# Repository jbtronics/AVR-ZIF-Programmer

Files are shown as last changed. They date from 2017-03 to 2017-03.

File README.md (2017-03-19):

# AVR-ZIF-Programmer

An Universal AVR Programmer with a ZIF-Socket and ISP Header based on [USBasp by Thomas Fischl](http://www.fischl.de/usbasp/).
The PCB was designed in [KiCAD](http://kicad-pcb.org/)

## Features:
* based on USBasp by Thomas Fischl
* ISP-Connector on PCB
* can Program many different AVRs:
  * ATMega 164/324/644/1284/16/32
  * ATMega 8/48/88/168/328
  * ATTiny 2313/4313
  * ATTiny 26/261/461/861
  * ATTiny 25/45/85/13
* socket for Crystal/active Clock Source
* main AVR can be updated/reflashed via USB
* LED shows data transfers

## License:
The PCB is licensed under the CERN OHL V1.2, the firmware and bootloader under GPLv2, see License files in the folders for details.

## Instructions
1. Use the Layout files (pcb/ folder) to order a PCB or made one by yourself.

2. Solder all components on it, except the Mega 8. I suggest to solder a socket for it instead. So you can replace it later (in case of wrong programming the "Master" CPU")

3. Put your Mega8 (or 88/168/328) in the ZIF socket in the right position for Mega8. Put the RESET-Jumper P5 in the Position PROG.

4. Now stick another ISP Programmer (you only need to do this once) into the ISP header on the board and flash the USBasp-Bootloader (bootloader/ folder) on it.

5. Put the flashed Mega 8 in its socket and stick an Jumper on the SLOW Header P2 and connect the board to the PC.

6. The Mega8 will be now in a bootloader mode, where it simulates an USBasp which flashes its own MCU. Use this "bootloader-USBasp" to flash the real USBasp Firmware (firmware/ folder). Now disconnect the SLOW-Header and reconnect the USB. Set the RESET-Header P5 into the GND Position.

Now you can use the board to flash other AVRs. With the RESET-Header P5 you can set if the RESET of the Target MCU should be controled from the Programmer or should be permanent on GND. I suggest using the GND position, so that the flashed MCU wont be damaged through short circuits (some Pins are connected to GND or VCC and the AVR would be damaged if it set that pins for example OUTPUT-HIGH on a GND-Pin).

When you want to flash an AVR that needs Crystal for Programming, you can stick one into the Crystal header P6. You can also connect an active Clock source in this, if you need it.

With setting SLOW-Header P2, you put the Mega8 into a bootloader mode, where you can reflash/update it.

## Gallery
### Renderings
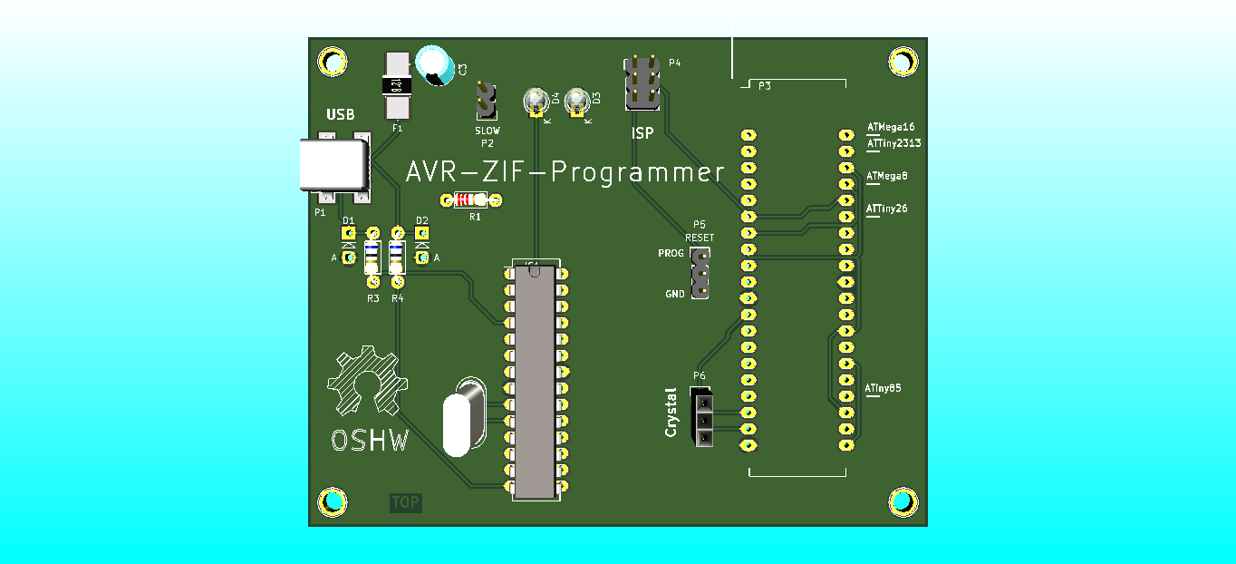
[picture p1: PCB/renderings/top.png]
top

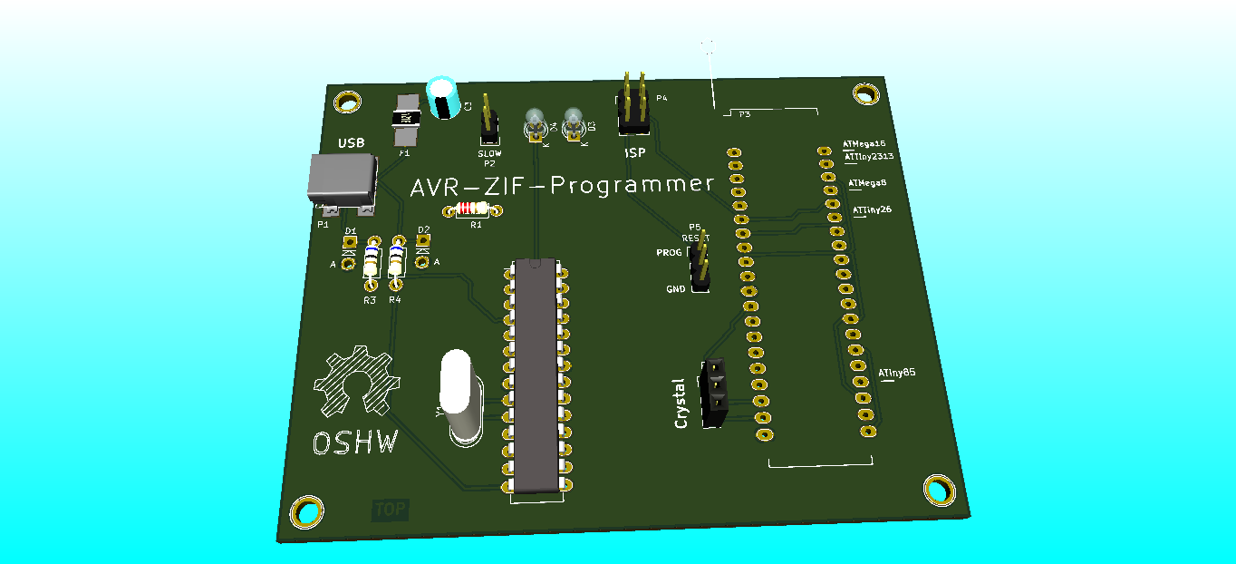
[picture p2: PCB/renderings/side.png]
side

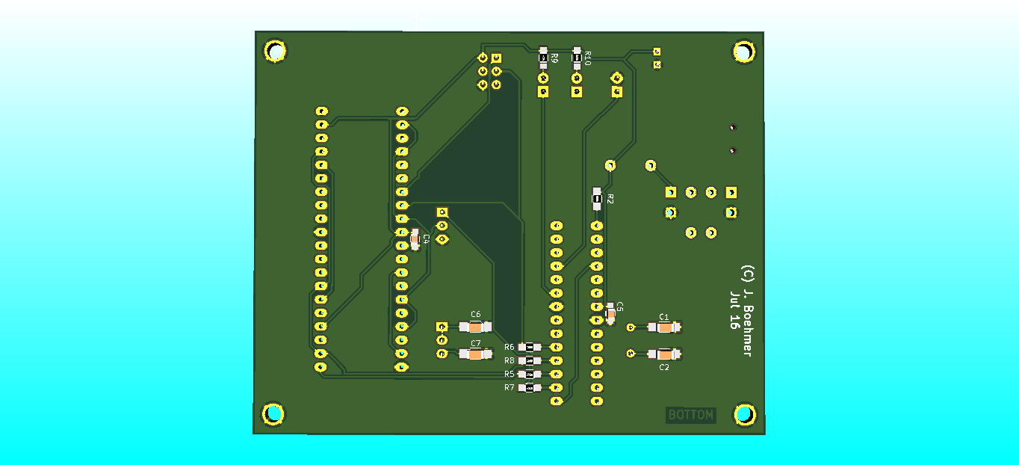
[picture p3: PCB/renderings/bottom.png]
bottom


## Links
[Hackaday.io](https://hackaday.io/project/9060-avr-zif-programmer) Page (for more infos and build instructions).

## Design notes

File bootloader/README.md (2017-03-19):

# AVR-ZIF-Programmer Bootloader

based on https://github.com/baerwolf/USBaspLoader
Licensed under GPLv2.

## Instructions
### Precompiled hex
You can flash the file "mega8_12MHz.hex" to your master MCU (Mega 8) and set the following fuses: `lfuse:0xbf` and `hfuse:0xd0`
### Build from source
Go into `firmware/` folder, open a console and type `make flash` to build and flash the bootloader, then type `make fuses` to burn the needed fuses.

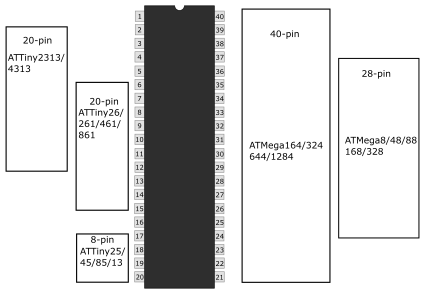
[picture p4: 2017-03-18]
PCB/pinout.png

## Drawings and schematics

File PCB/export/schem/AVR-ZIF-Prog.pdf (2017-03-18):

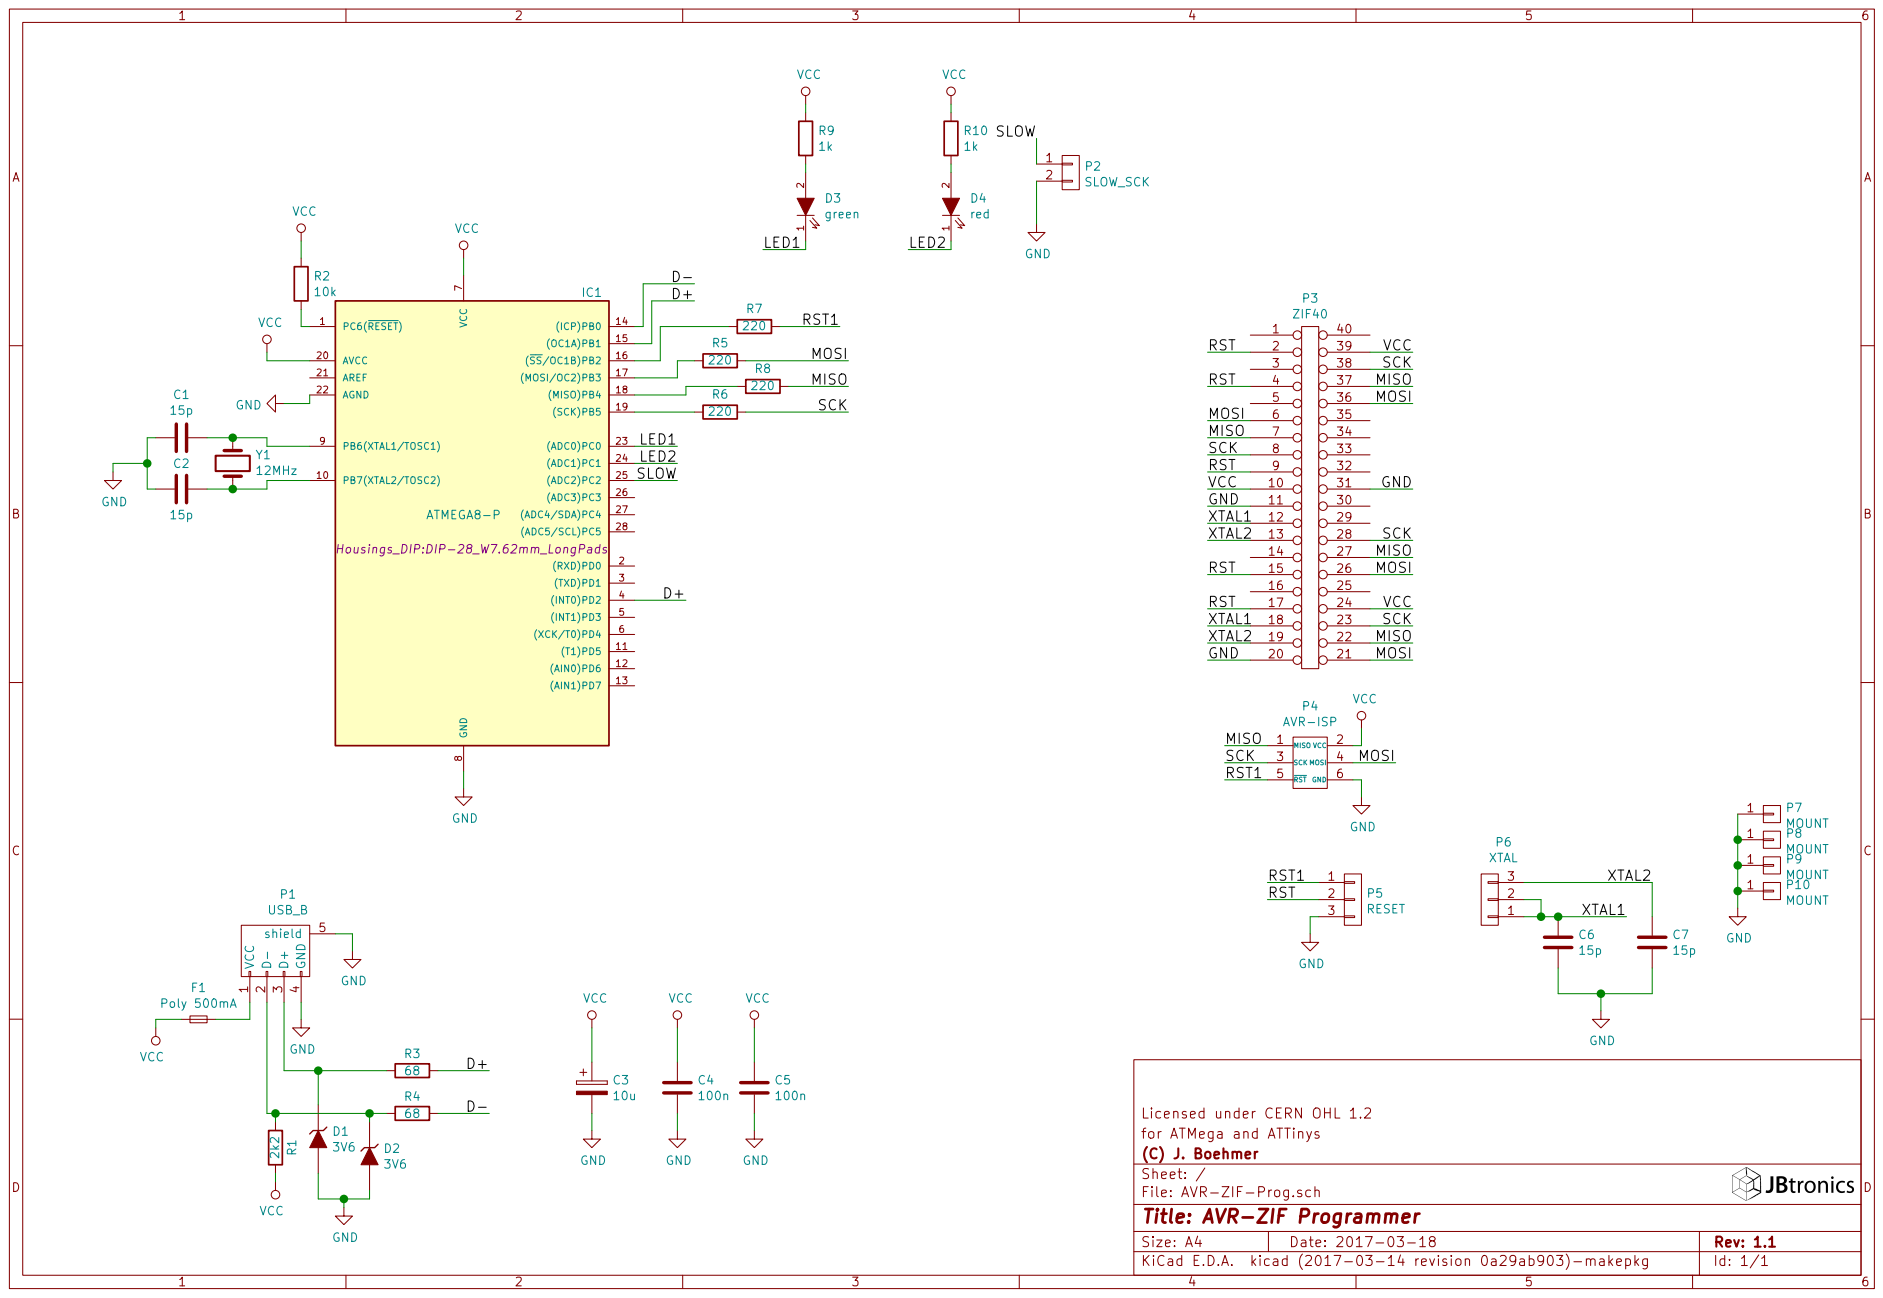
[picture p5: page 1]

18 | 23
19 | 22

MOSI VCC GND VCC

for ATMega and ATTinys Licensed under CERN OHL 1.2

File: AVR-ZIF-Prog.sch Sheet: / (C) J. Boehmer

Id: 1/1 Title: AVR-ZIF Programmer

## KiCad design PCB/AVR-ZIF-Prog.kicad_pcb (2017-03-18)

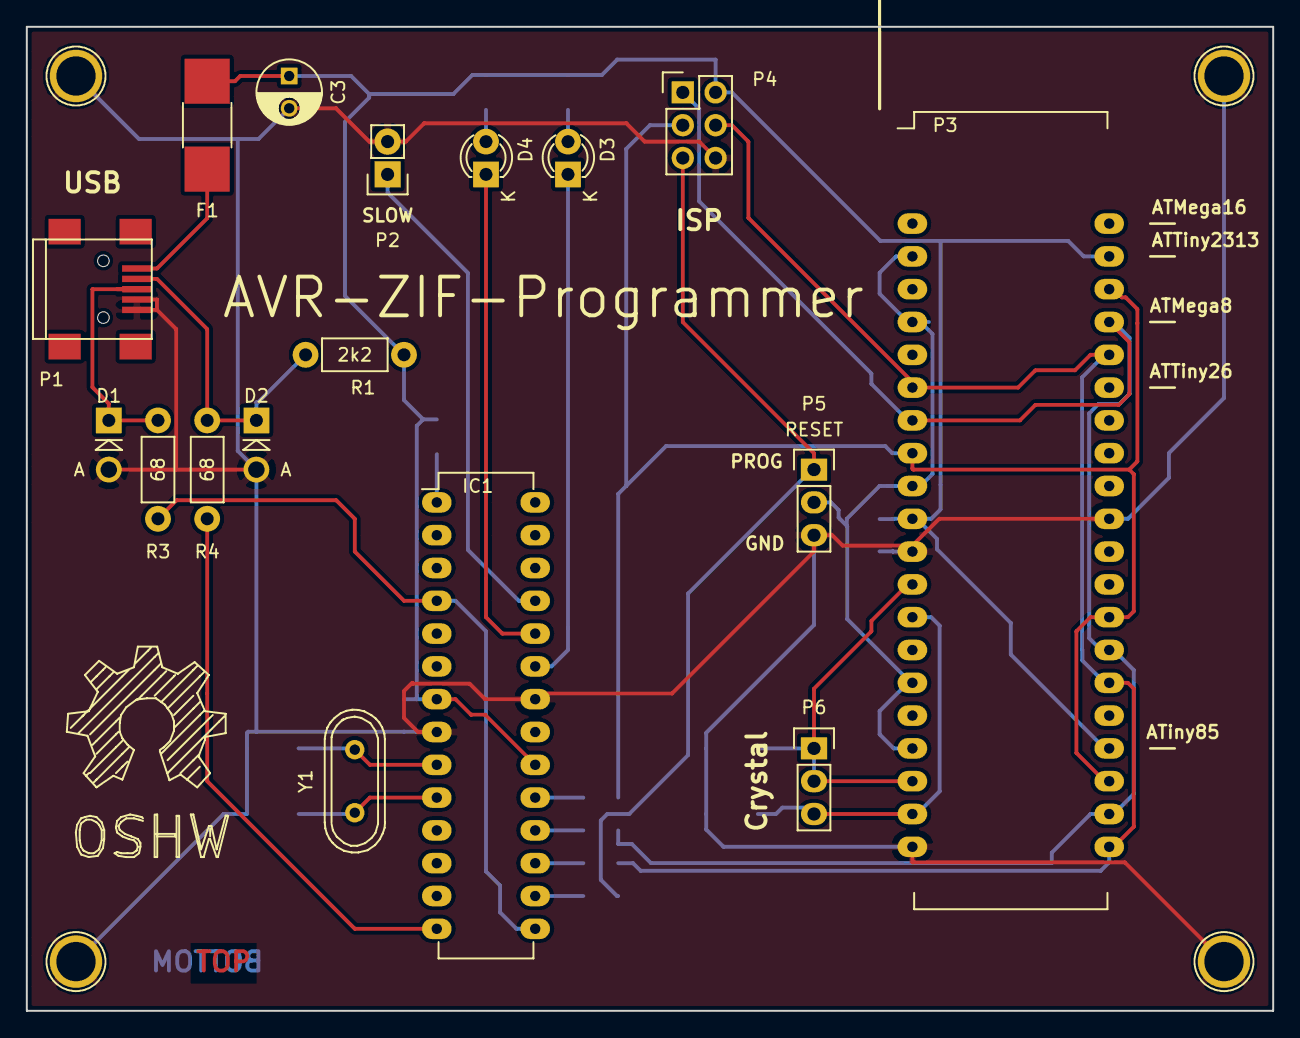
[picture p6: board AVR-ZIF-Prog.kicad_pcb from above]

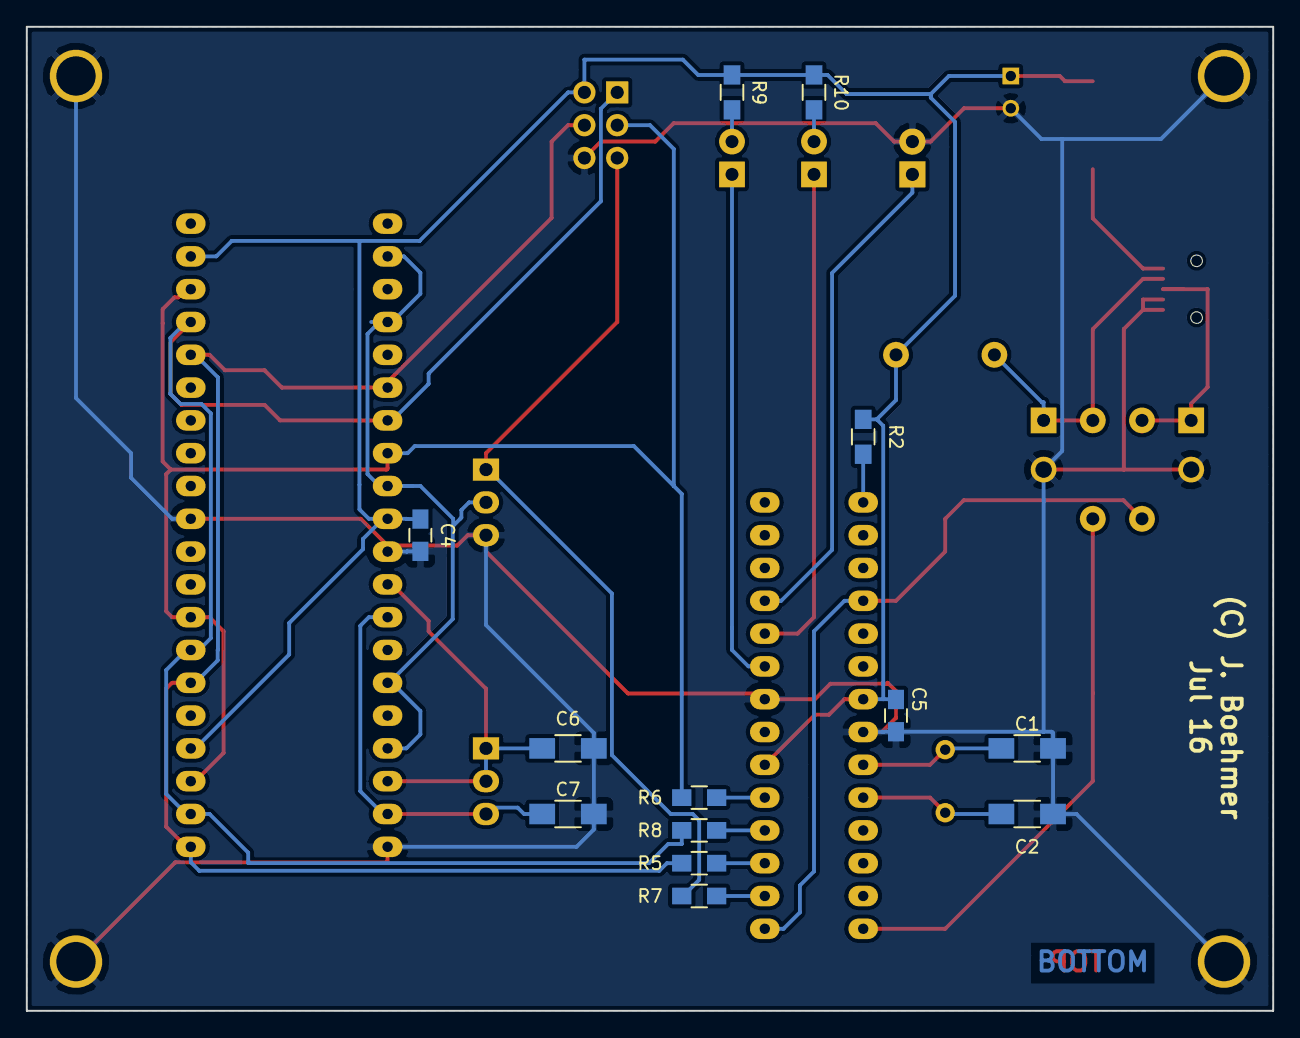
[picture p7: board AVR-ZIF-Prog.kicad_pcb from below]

Board: 2 copper layers, 96.5 x 76.2 mm, 34 parts (13 on the bottom side), 26 nets.

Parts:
C1, C2, C6, C7: 15p; C_1206_HandSoldering
C3: 10u; C_Radial_D5_L6_P2.5
C4, C5: 100n; C_0805_HandSoldering
D1, D2: 3V6; Diode_DO-41_SOD81_Vertical_AnodeUp
D3: green; LED-3MM
D4: red; LED-3MM
F1: Poly 500mA; R_1812_HandSoldering
IC1: ATMEGA8-P; DIP-28_W7.62mm_LongPads
P1: USB_B; USB_Mini-B
P2: SLOW_SCK; Pin_Header_Straight_1x02
P3: ZIF40; ZIF-40_W15.24mm_LongPads
P4: AVR-ISP; Pin_Header_Straight_2x03
P5: RESET; Pin_Header_Straight_1x03
P6: XTAL; Socket_Strip_Straight_1x03
P7, P8, P9, P10: MOUNT; 1pin
R1: 2k2; Resistor_Horizontal_RM7mm
R2: 10k; R_0805_HandSoldering
R3, R4: 68; Resistor_Horizontal_RM7mm
R5, R6, R7, R8: 220; R_0805_HandSoldering
R9, R10: 1k; R_0805_HandSoldering
Y1: 12MHz; Crystal_HC49-U_Vertical

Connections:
/D+: IC1.4, IC1.15, R3.1
/D-: IC1.14, R4.1
/LED1: D3.1, IC1.23
/LED2: D4.1, IC1.24
/MISO: P3.7, P3.22, P3.27, P3.37, P4.1, R8.2
/MOSI: P3.6, P3.21, P3.26, P3.36, P4.4, R5.2
/RST: P3.2, P3.4, P3.9, P3.15, P3.17, P5.2
/RST1: P4.5, P5.1, R7.2
/SCK: P3.8, P3.23, P3.28, P3.38, P4.3, R6.2
/SLOW: IC1.25, P2.1
/XTAL1: C6.1, P3.12, P3.18, P6.1, P6.2
/XTAL2: C7.1, P3.13, P3.19, P6.3
GND: C1.2, C2.1, C3.2, C4.2, C5.2, C6.2, C7.2, D1.2, D2.2, IC1.8, IC1.22, P1.4, P1.5, P2.2, P3.11, P3.20, P3.31, P4.6, P5.3, P7.1, P8.1, P9.1, P10.1
unnamed: C1.1, IC1.9, Y1.2
unnamed: C2.2, IC1.10, Y1.1
unnamed: D1.1, P1.3, R3.2
unnamed: D2.1, P1.2, R1.2, R4.2
unnamed: D3.2, R9.2
unnamed: D4.2, R10.2
unnamed: F1.2, P1.1
unnamed: IC1.1, R2.2
unnamed: IC1.16, R7.1
unnamed: IC1.17, R5.1
unnamed: IC1.18, R8.1
unnamed: IC1.19, R6.1
VCC: C3.1, C4.1, C5.1, F1.1, IC1.7, IC1.20, P3.10, P3.24, P3.39, P4.2, R1.1, R2.1, R9.1, R10.1

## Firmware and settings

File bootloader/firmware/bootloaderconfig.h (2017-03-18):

/* Name: bootloaderconfig.h
 * Project: USBaspLoader
 * Author: Christian Starkjohann
 * Author: Stephan Baerwolf
 * Creation Date: 2007-12-08
 * Modification Date: 2013-03-31
 * Tabsize: 4
 * Copyright: (c) 2007 by OBJECTIVE DEVELOPMENT Software GmbH
 * License: GNU GPL v2 (see License.txt)
 */

#ifndef __bootloaderconfig_h_included__
#define __bootloaderconfig_h_included__
#include "../misc/iofixes.h"

/*
General Description:
This file (together with some settings in Makefile) configures the boot loader
according to the hardware.

This file contains (besides the hardware configuration normally found in
usbconfig.h) two functions or macros: bootLoaderInit() and
bootLoaderCondition(). Whether you implement them as macros or as static
inline functions is up to you, decide based on code size and convenience.

bootLoaderInit() is called as one of the first actions after reset. It should
be a minimum initialization of the hardware so that the boot loader condition
can be read. This will usually consist of activating a pull-up resistor for an
external jumper which selects boot loader mode.

bootLoaderCondition() is called immediately after initialization and in each
main loop iteration. If it returns TRUE, the boot loader will be active. If it
returns FALSE, the boot loader jumps to address 0 (the loaded application)
immediately.

For compatibility with Thomas Fischl's avrusbboot, we also support the macro
names BOOTLOADER_INIT and BOOTLOADER_CONDITION for this functionality. If
these macros are defined, the boot loader usees them.
*/

/* ---------------------------- Macro Magic ---------------------------- */
#define		PIN_CONCAT(a,b)			a ## b
#define		PIN_CONCAT3(a,b,c)		a ## b ## c

#define		PIN_PORT(a)			PIN_CONCAT(PORT, a)
#define		PIN_PIN(a)			PIN_CONCAT(PIN, a)
#define		PIN_DDR(a)			PIN_CONCAT(DDR, a)

#define		PIN(a, b)			PIN_CONCAT3(P, a, b)

/* ---------------------------- Hardware Config ---------------------------- */

#ifndef USB_CFG_IOPORTNAME
  #define USB_CFG_IOPORTNAME      B
#endif
/* This is the port where the USB bus is connected. When you configure it to
 * "B", the registers PORTB, PINB and DDRB will be used.
 */
#ifndef USB_CFG_INTPORT_BIT
  #if (defined(__AVR_ATmega640__) || defined (__AVR_ATmega128__) || defined(__AVR_ATmega1280__) || defined(__AVR_ATmega1281__) || defined(__AVR_ATmega2560__) || defined(__AVR_ATmega2561__))
    #define USB_CFG_INTPORT_BIT 0
  #else
    #define USB_CFG_INTPORT_BIT 0
  #endif
#endif
/* Not all devices have their INT0 on PD2.
 * Since "INT0" and "USB_CFG_DPLUS_BIT" should get the same signals,
 * map them to be ideally the same:
 * So abstract "USB_CFG_DPLUS_BIT" to this one here.
 */

#ifndef USB_CFG_DMINUS_BIT
  /* This is Revision 3 and later (where PD6 and PD7 were swapped */
  #define USB_CFG_DMINUS_BIT      0    /* Rev.2 and previous was 6 */
#endif
/* This is the bit number in USB_CFG_IOPORT where the USB D- line is connected.
 * This may be any bit in the port.
 */
#ifndef USB_CFG_DPLUS_BIT
  #define USB_CFG_DPLUS_BIT       1
#endif
/* This is the bit number in USB_CFG_IOPORT where the USB D+ line is connected.
 * This may be any bit in the port. Please note that D+ must also be connected
 * to interrupt pin INT0!
 */
#ifndef JUMPER_PORT
  #define JUMPER_PORT		C
#endif
/* 
 * jumper is connected to this port
 */
#ifndef JUMPER_BIT
  /* This is Revision 3 and later (where PD6 and PD7 were swapped */
  #define JUMPER_BIT           2       /* Rev.2 and previous was 7 */
#endif
/* 
 * jumper is connected to this bit in port "JUMPER_PORT", active low
 */

#define USB_CFG_CLOCK_KHZ       (F_CPU/1000)
/* Clock rate of the AVR in MHz. Legal values are 12000, 16000 or 16500.
 * The 16.5 MHz version of the code requires no crystal, it tolerates +/- 1%
 * deviation from the nominal frequency. All other rates require a precision
 * of 2000 ppm and thus a crystal!
 * Default if not specified: 12 MHz
 */

/* ----------------------- Optional Hardware Config ------------------------ */

/* #define USB_CFG_PULLUP_IOPORTNAME   D */
/* If you connect the 1.5k pullup resistor from D- to a port pin instead of
 * V+, you can connect and disconnect the device from firmware by calling
 * the macros usbDeviceConnect() and usbDeviceDisconnect() (see usbdrv.h).
 * This constant defines the port on which the pullup resistor is connected.
 */
/* #define USB_CFG_PULLUP_BIT          4 */
/* This constant defines the bit number in USB_CFG_PULLUP_IOPORT (defined
 * above) where the 1.5k pullup resistor is connected. See description
 * above for details.
 */

/* ------------------------------------------------------------------------- */
/* ---------------------- feature / code size options ---------------------- */
/* ------------------------------------------------------------------------- */
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

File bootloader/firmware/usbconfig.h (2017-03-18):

/* Name: usbconfig.h
 * Project: V-USB, virtual USB port for Atmel's(r) AVR(r) microcontrollers
 * Author: Christian Starkjohann
 * Creation Date: 2005-04-01
 * Tabsize: 4
 * Copyright: (c) 2005 by OBJECTIVE DEVELOPMENT Software GmbH
 * License: GNU GPL v2 (see License.txt), GNU GPL v3 or proprietary (CommercialLicense.txt)
 */

#ifndef __usbconfig_h_included__
#define __usbconfig_h_included__

/* YOU SHOULD NOT NEED TO MODIFY THIS FILE! All configurations are supposed
 * to go into bootloaderconfig.h!
 */

/* ---------------------------- Hardware Config ---------------------------- */

/* All the port and pin assignments, as well as the clock speed and CRC
   setting are now in bootloaderconfig.h: */

#include "bootloaderconfig.h"

/* --------------------------- Functional Range ---------------------------- */

#define USB_CFG_HAVE_INTRIN_ENDPOINT    0
/* Define this to 1 if you want to compile a version with two endpoints: The
 * default control endpoint 0 and an interrupt-in endpoint (any other endpoint
 * number).
 */
#define USB_CFG_HAVE_INTRIN_ENDPOINT3   0
/* Define this to 1 if you want to compile a version with three endpoints: The
 * default control endpoint 0, an interrupt-in endpoint 3 (or the number
 * configured below) and a catch-all default interrupt-in endpoint as above.
 * You must also define USB_CFG_HAVE_INTRIN_ENDPOINT to 1 for this feature.
 */
#define USB_CFG_EP3_NUMBER              3
/* If the so-called endpoint 3 is used, it can now be configured to any other
 * endpoint number (except 0) with this macro. Default if undefined is 3.
 */
/* #define USB_INITIAL_DATATOKEN           USBPID_DATA1 */
/* The above macro defines the startup condition for data toggling on the
 * interrupt/bulk endpoints 1 and 3. Defaults to USBPID_DATA1.
 * Since the token is toggled BEFORE sending any data, the first packet is
 * sent with the oposite value of this configuration!
 */
#define USB_CFG_IMPLEMENT_HALT          0
/* Define this to 1 if you also want to implement the ENDPOINT_HALT feature
 * for endpoint 1 (interrupt endpoint). Although you may not need this feature,
 * it is required by the standard. We have made it a config option because it
 * bloats the code considerably.
 */
#define USB_CFG_SUPPRESS_INTR_CODE      0
/* Define this to 1 if you want to declare interrupt-in endpoints, but don't
 * want to send any data over them. If this macro is defined to 1, functions
 * usbSetInterrupt() and usbSetInterrupt3() are omitted. This is useful if
 * you need the interrupt-in endpoints in order to comply to an interface
 * (e.g. HID), but never want to send any data. This option saves a couple
 * of bytes in flash memory and the transmit buffers in RAM.
 */
#define USB_CFG_INTR_POLL_INTERVAL      10
/* If you compile a version with endpoint 1 (interrupt-in), this is the poll
 * interval. The value is in milliseconds and must not be less than 10 ms for
 * low speed devices.
 */
#ifndef USB_CFG_IS_SELF_POWERED // allow bootloaderconfig.h to override
#define USB_CFG_IS_SELF_POWERED         0
#endif
/* Define this to 1 if the device has its own power supply. Set it to 0 if the
 * device is powered from the USB bus.
 */
#ifndef USB_CFG_MAX_BUS_POWER   // allow bootloaderconfig.h to override
#define USB_CFG_MAX_BUS_POWER           200
#endif
/* Set this variable to the maximum USB bus power consumption of your device.
 * The value is in milliamperes. [It will be divided by two since USB
 * communicates power requirements in units of 2 mA.]
 */
#define USB_CFG_IMPLEMENT_FN_WRITE      1
/* Set this to 1 if you want usbFunctionWrite() to be called for control-out
 * transfers. Set it to 0 if you don't need it and want to save a couple of
 * bytes.
 */
#define USB_CFG_IMPLEMENT_FN_READ       1
/* Set this to 1 if you need to send control replies which are generated
 * "on the fly" when usbFunctionRead() is called. If you only want to send
 * data from a static buffer, set it to 0 and return the data from
 * usbFunctionSetup(). This saves a couple of bytes.
 */
#define USB_CFG_IMPLEMENT_FN_WRITEOUT   0
/* Define this to 1 if you want to use interrupt-out (or bulk out) endpoints.
 * You must implement the function usbFunctionWriteOut() which receives all
 * interrupt/bulk data sent to any endpoint other than 0. The endpoint number
 * can be found in 'usbRxToken'.
 */
#define USB_CFG_HAVE_FLOWCONTROL        0
/* Define this to 1 if you want flowcontrol over USB data. See the definition
 * of the macros usbDisableAllRequests() and usbEnableAllRequests() in
 * usbdrv.h.
 */
#if defined(BOOTLOADER_ADDRESS)
#	define USB_CFG_DRIVER_FLASH_PAGE       (BOOTLOADER_ADDRESS >> 16)
#else
#	define USB_CFG_DRIVER_FLASH_PAGE       0
#endif
/* If the device has more than 64 kBytes of flash, define this to the 64 k page
 * where the driver's constants (descriptors) are located. Or in other words:
 * Define this to 1 for boot loaders on the ATMega128.
 */
#define USB_CFG_LONG_TRANSFERS          0
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
